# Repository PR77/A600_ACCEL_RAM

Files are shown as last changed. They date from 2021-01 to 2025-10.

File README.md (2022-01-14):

# A600_ACCEL_RAM
Design attempt for an Amiga 600 over CPU (PLCC) 68000 Accelerator including 1.5MB FastRAM (... or is it SlowRAM) and 0.5MB MapROM support.

# Warning
This design has not been compliance tested and will not be. It may cause damage to your A600. I take no responsibility for this. I accept no responsibility for any damage to any equipment that results from the use of this design and its components. IT IS ENTIRELY AT YOUR OWN RISK!

# Overview
The main purpose of this design was to develop a simple, affordable and efficient Accelerator, FastRAM and MapROM support device for the Amiga 600. The main components of the design and the CPU (MC68SEC000), CPLD (9572) and SRAM (CY62167G). There are the odd LEDs for status and some IO Pins for currently unplanned additions. As discovered in my A500 Accelerator the MC68SEC000 can be aggressively clocked and this design does not detour from that.

### Appearance
Nice 3D model:
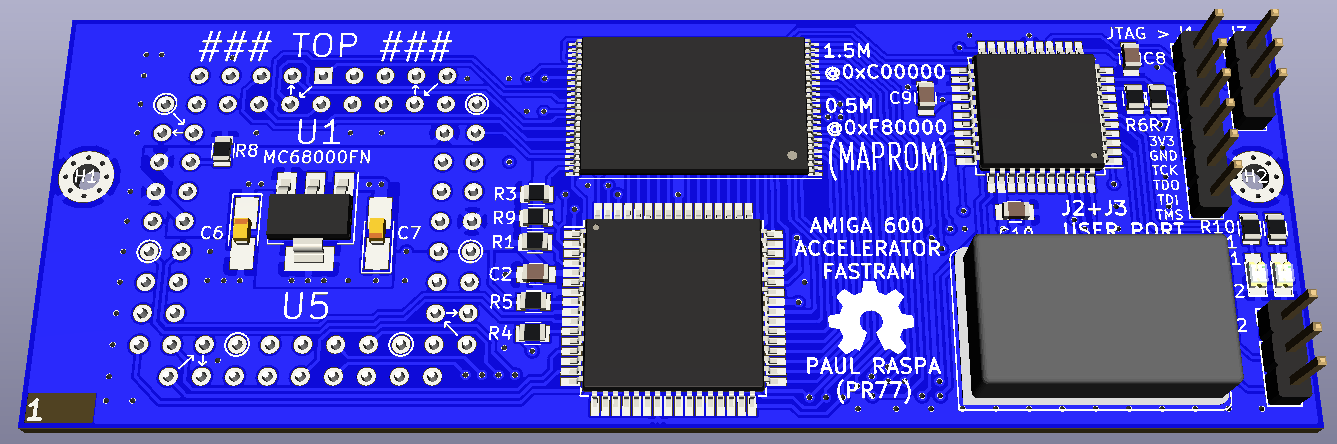
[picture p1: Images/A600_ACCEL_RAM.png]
3D Model


Installed on A600 Motherboard:
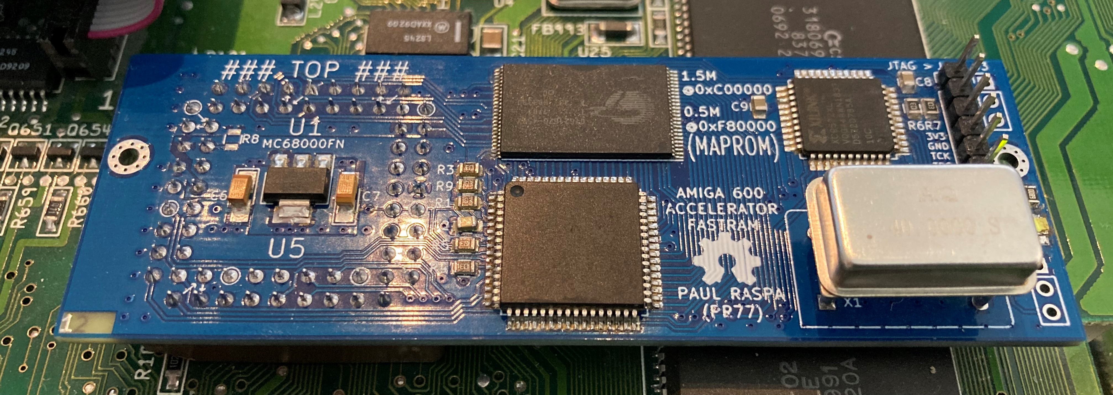
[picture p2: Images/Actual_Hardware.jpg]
Actual Hardware


Mounting holes on the Accelerator PCB match with the HDD cradle and accommodate a M2 screw to provide stress relief for the PLCC68 socket. SukkoPera has a great guide on how to prepare the PLCC68 socket as some small modifications are required. His how to guide is linked here;

https://github.com/SukkoPera/OpenAmiga600FastRamExpansion/blob/master/SocketRework.md

### Performance
Testing has shown that the A600 system is fairly stable at 40MHz. Slower crystals can be used if stability is an issue (let me know if you run into issues). I've had the classic Amiga Juggler running for 48 Hours without any issues. Classic SysInfo shows @ 40MHz (with MapROM active);

* Drystones: 3448
* MIPS: 3.59
* Comment: Only Amiga Makes.. 

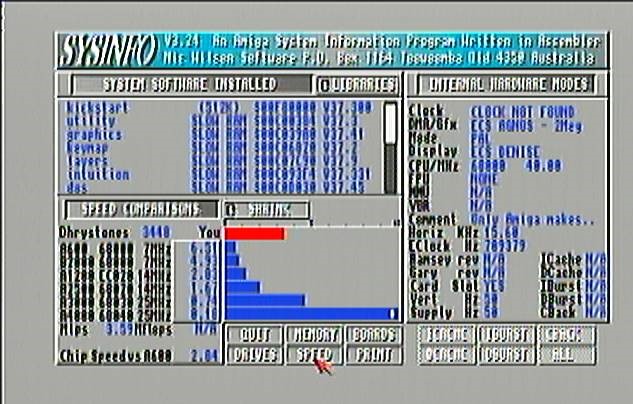
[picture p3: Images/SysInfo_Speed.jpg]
SysInfo Speed


IDE (via GAYLE's scsi.device) also shows a nice speed improvement with a CF Card:

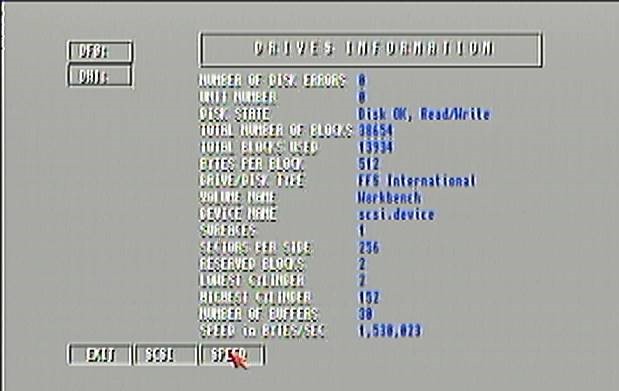
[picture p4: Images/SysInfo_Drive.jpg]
SysInfo Drive


### BOM
For those wanting to build their own hardware, here is the BOM;

| Reference(s)  | Value | Footprint |
|---|---|---|
|C1 | 100n |Capacitors_SMD:C_0805
|C2 | 100n |Capacitors_SMD:C_0805
|C3 | 100n |Capacitors_SMD:C_0805
|C4 | 100n |Capacitors_SMD:C_0805
|C6 | 10u |Capacitors_Tantalum_SMD:CP_Tantalum_Case-R_EIA-2012-12_Hand
|C7 | 10u |Capacitors_Tantalum_SMD:CP_Tantalum_Case-R_EIA-2012-12_Hand
|C8 | 100n |Capacitors_SMD:C_0805
|C9 | 100n |Capacitors_SMD:C_0805
|C10 | 100n |Capacitors_SMD:C_0805
|D1 | LED |LEDs:LED_0805
|D2 | LED |LEDs:LED_0805
|J1 | JTAG |Connector:Conn_01x06_Male","Pin_Headers:Pin_Header_Straight_1x06_Pitch2.54mm
|J2 (not loaded)| SPARE1 |Connector:Conn_01x03_Male","Pin_Headers:Pin_Header_Straight_1x03_Pitch2.54mm
|J3 (not loaded)| SPARE2 |Connector:Conn_01x03_Male","Pin_Headers:Pin_Header_Straight_1x03_Pitch2.54mm
|R1 | 10K |Resistors_SMD:R_0805
|R3 | 10K |Resistors_SMD:R_0805
|R4 | 10K |Resistors_SMD:R_0805
|R5 | 10K |Resistors_SMD:R_0805
|R6 | 10K |Resistors_SMD:R_0805
|R7 | 10K |Resistors_SMD:R_0805
|R8 (not loaded)| 10K |Resistors_SMD:R_0805
|R9 | 10K |Resistors_SMD:R_0805
|R10 | 680R |Resistors_SMD:R_0805
|R11 | 680R |Resistors_SMD:R_0805
|U1 | SOCKET |PLCC-68_THT-SocketUpsideDown
|U2 | MC68SEC000 |Housings_QFP:LQFP-64_14x14mm_Pitch0.8mm
|U3 | CY62167G |Housings_SSOP:TSOP-I-48_18.4x12mm_Pitch0.5mm
|U4 | XC9572VQ44 |Housings_QFP:LQFP-44_10x10mm_Pitch0.8mm
|U5 | LM1117-3.3 |TO_SOT_Packages_SMD:SOT-223-3_TabPin2
|X1 | CXO_DIP14 |Oscillators:Oscillator_DIP-14

### CPU
Regarding the CPU, I purchased from here (I get nothing from this. The parts I received were new and legitimate so I wanted to share the source);

https://www.ebay.de/itm/MC68SEC000FU20-IC-MPU-M680X0-20MHZ-64QFP-NEW/311524970603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

### LED Indicators
2 LED indicators are present:

* ACCEL ACTIVE: This indicates that a Bus Request (BR) was requested by the MC68SEC000 Accelerator CPU and Granted (/BG) by the Amiga's MC68000 CPU.
* MAPROM ACTIVE: After writing a 512K MapROM image to the Accelerator, the next subsequent Reset will active this image. This LED indicates that the MapROM image is in use.

### FastRAM (... or is it SlowRAM)
To simplify the design and keep the CPLD pin count down, I decided not to use traditional FastRAM, rather use SlowRAM which is automatically mapped by the Amiga if valid memory is detected between 0xC00000 - 0xD7FFFF. In this range 1.5MB is available. In this memory range, the Accelerator performs the address decoding and subsequent /DTACK cycle. /AS is not asserted on the Amiga, thus the speed of memory cycles in this range is equivalent to that of FastRAM.

### MapROM
Of the 2MB RAM available, 1.5MB is allocated to SlowRAM and the remainder is allocated for MapROM. MapROM simply works by routing write cycle to 0xF8xxxx directly to the Accelerators RAM. Once enough write cycles are detected (262144 WORD writes), the MapROM write status is latched. After a subsequent Reset, memory accesses to 0xF8xxxx are directly routed to the Accelerators RAM (at full speed) and /AS is not asserted on the Amiga.

To deactive MapROM, simply hold down CTRL-A-A for 1 second and it will be deactivated. A different image could then be loaded. Note, once an image is loaded it needs to be deactivated again before a different image can be used. DiagROM images could also be used - helpful to avoid swapping out the physical ROM chip.

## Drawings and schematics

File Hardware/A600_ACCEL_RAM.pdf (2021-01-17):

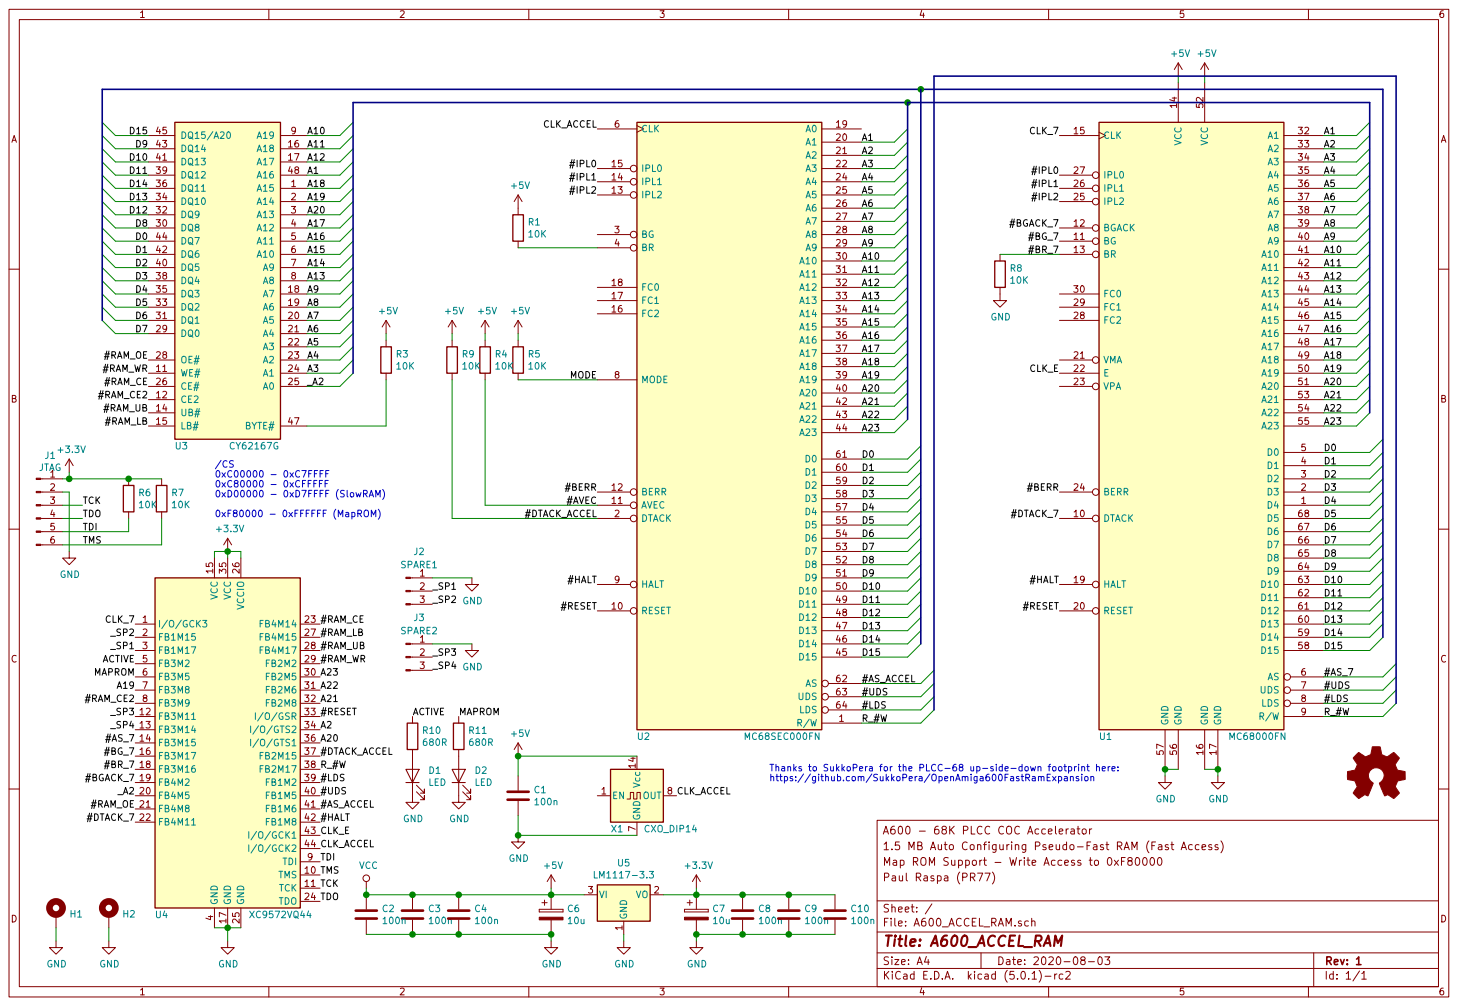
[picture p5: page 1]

Thanks to SukkoPera for the PLCC-68 up-side-down footprint here:

https://github.com/SukkoPera/OpenAmiga600FastRamExpansion VCC

Map ROM Support - Write Access to 0xF80000
File: A600_ACCEL_RAM.sch Sheet: / Paul Raspa (PR77)

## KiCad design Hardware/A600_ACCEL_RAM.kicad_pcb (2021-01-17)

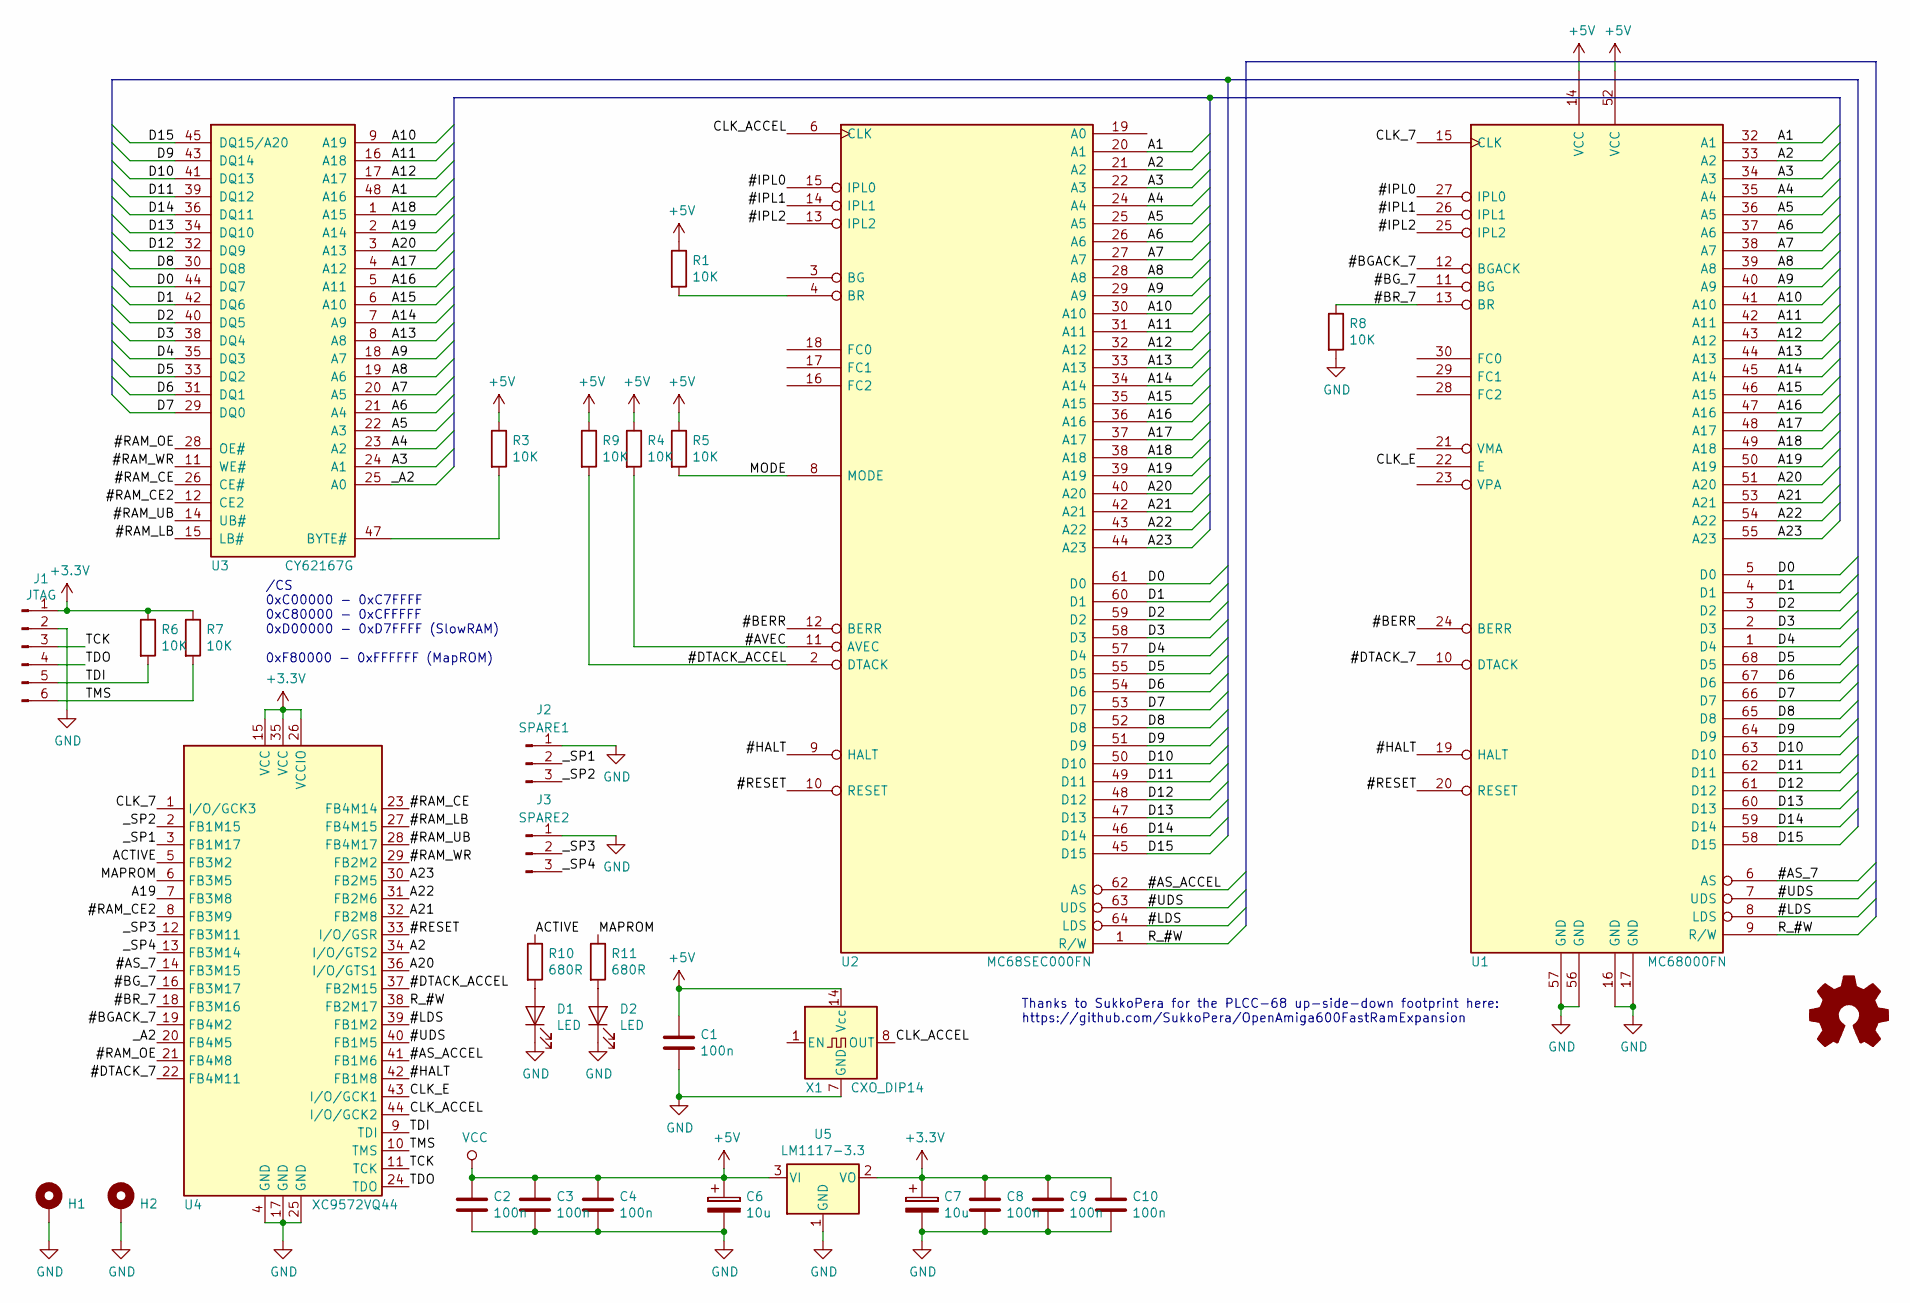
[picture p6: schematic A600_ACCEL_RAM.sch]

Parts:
C1, C2, C3, C4, C8, C9, C10: 100n; C_0805
C6, C7: 10u; CP_Tantalum_Case-R_EIA-2012-12_Hand
D1, D2: LED; LED_0805
H1, H2: MountingHole_Pad; MountingHole_2.2mm_M2_Pad_Via
J1: JTAG; Pin_Header_Straight_1x06_Pitch2.54mm
J2: SPARE1; Pin_Header_Straight_1x03_Pitch2.54mm
J3: SPARE2; Pin_Header_Straight_1x03_Pitch2.54mm
LOGO1: OSHW; OSHW-Symbol_6.7x6mm_SilkScreen
R1, R3, R4, R5, R6, R7, R8, R9: 10K; R_0805
R10, R11: 680R; R_0805
U1: MC68000FN; PLCC-68_THT-SocketUpsideDown
U2: MC68SEC000FN; LQFP-64_14x14mm_Pitch0.8mm
U3: CY62167G; TSOP-I-48_18.4x12mm_Pitch0.5mm
U4: XC9572VQ44; LQFP-44_10x10mm_Pitch0.8mm
U5: LM1117-3.3; SOT-223-3_TabPin2
X1: CXO_DIP14; Oscillator_DIP-14

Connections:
+3V3: C7.1, C8.1, C9.1, C10.1, J1.1, R6.1, R7.1, U4.15 (VCC), U4.26 (VCCIO), U4.35 (VCC), U5.2 (VO)
+5V: C1.1, C2.1, C3.1, C4.1, C6.1, R1.1, R3.1, R4.1, R5.1, R9.1, U1.14 (VCC), U1.52 (VCC), U2.5 (VCC), U2.41 (VCC), U3.37 (VCC), U5.3 (VI), X1.14 (Vcc)
/#AS_7: U1.6 (AS), U4.14 (FB3M15)
/#AS_ACCEL: U2.62 (AS), U4.41 (FB1M6)
/#AVEC: R4.2, U2.11 (AVEC)
/#BERR: U1.24 (BERR), U2.12 (BERR)
/#BGACK_7: U1.12 (BGACK), U4.19 (FB4M2)
/#BG_7: U1.11 (BG), U4.16 (FB3M17)
/#BR_7: R8.1, U1.13 (BR), U4.18 (FB3M16)
/#DTACK_7: U1.10 (DTACK), U4.22 (FB4M11)
/#DTACK_ACCEL: R9.2, U2.2 (DTACK), U4.37 (FB2M15)
/#HALT: U1.19 (HALT), U2.9 (HALT), U4.42 (FB1M8)
/#IPL0: U1.27 (IPL0), U2.15 (IPL0)
/#IPL1: U1.26 (IPL1), U2.14 (IPL1)
/#IPL2: U1.25 (IPL2), U2.13 (IPL2)
/#LDS: U1.8 (LDS), U2.64 (LDS), U4.39 (FB1M2)
/#RAM_CE: U3.26 (CE#), U4.23 (FB4M14)
/#RAM_CE2: U3.12 (CE2), U4.8 (FB3M9)
/#RAM_LB: U3.15 (LB#), U4.27 (FB4M15)
/#RAM_OE: U3.28 (OE#), U4.21 (FB4M8)
/#RAM_UB: U3.14 (UB#), U4.28 (FB4M17)
/#RAM_WR: U3.11 (WE#), U4.29 (FB2M2)
/#RESET: U1.20 (RESET), U2.10 (RESET), U4.33 (I/O/GSR)
/#UDS: U1.7 (UDS), U2.63 (UDS), U4.40 (FB1M5)
/A1: U1.32 (A1), U2.20 (A1), U3.48 (A16)
/A2: U1.33 (A2), U2.21 (A2), U4.34 (I/O/GTS2)
/A3: U1.34 (A3), U2.22 (A3), U3.24 (A1)
/A4: U1.35 (A4), U2.24 (A4), U3.23 (A2)
/A5: U1.36 (A5), U2.25 (A5), U3.22 (A3)
/A6: U1.37 (A6), U2.26 (A6), U3.21 (A4)
/A7: U1.38 (A7), U2.27 (A7), U3.20 (A5)
/A8: U1.39 (A8), U2.28 (A8), U3.19 (A6)
/A9: U1.40 (A9), U2.29 (A9), U3.18 (A7)
/A10: U1.41 (A10), U2.30 (A10), U3.9 (A19)
/A11: U1.42 (A11), U2.31 (A11), U3.16 (A18)
/A12: U1.43 (A12), U2.32 (A12), U3.17 (A17)
/A13: U1.44 (A13), U2.33 (A13), U3.8 (A8)
/A14: U1.45 (A14), U2.34 (A14), U3.7 (A9)
/A15: U1.46 (A15), U2.35 (A15), U3.6 (A10)
/A16: U1.47 (A16), U2.36 (A16), U3.5 (A11)
/A17: U1.48 (A17), U2.37 (A17), U3.4 (A12)
/A18: U1.49 (A18), U2.38 (A18), U3.1 (A15)
/A19: U1.50 (A19), U2.39 (A19), U3.2 (A14), U4.7 (FB3M8)
/A20: U1.51 (A20), U2.40 (A20), U3.3 (A13), U4.36 (I/O/GTS1)
/A21: U1.53 (A21), U2.42 (A21), U4.32 (FB2M8)
/A22: U1.54 (A22), U2.43 (A22), U4.31 (FB2M6)
/A23: U1.55 (A23), U2.44 (A23), U4.30 (FB2M5)
/ACTIVE: R10.1, U4.5 (FB3M2)
/CLK_7: U1.15 (CLK), U4.1 (I/O/GCK3)
/CLK_ACCEL: U2.6 (CLK), U4.44 (I/O/GCK2), X1.8 (OUT)
/CLK_E: U1.22 (E), U4.43 (I/O/GCK1)
/D0: U1.5 (D0), U2.61 (D0), U3.44 (DQ7)
/D1: U1.4 (D1), U2.60 (D1), U3.42 (DQ6)
/D2: U1.3 (D2), U2.59 (D2), U3.40 (DQ5)
/D3: U1.2 (D3), U2.58 (D3), U3.38 (DQ4)
/D4: U1.1 (D4), U2.57 (D4), U3.35 (DQ3)
/D5: U1.68 (D5), U2.55 (D5), U3.33 (DQ2)
/D6: U1.67 (D6), U2.54 (D6), U3.31 (DQ1)
/D7: U1.66 (D7), U2.53 (D7), U3.29 (DQ0)
/D8: U1.65 (D8), U2.52 (D8), U3.30 (DQ8)
/D9: U1.64 (D9), U2.51 (D9), U3.43 (DQ14)
/D10: U1.63 (D10), U2.50 (D10), U3.41 (DQ13)
/D11: U1.62 (D11), U2.49 (D11), U3.39 (DQ12)
/D12: U1.61 (D12), U2.48 (D12), U3.32 (DQ9)
/D13: U1.60 (D13), U2.47 (D13), U3.34 (DQ10)
/D14: U1.59 (D14), U2.46 (D14), U3.36 (DQ11)
/D15: U1.58 (D15), U2.45 (D15), U3.45 (DQ15/A20)
/MAPROM: R11.1, U4.6 (FB3M5)
/MODE: R5.2, U2.8 (MODE)
/R_#W: U1.9 (R/W), U2.1 (R/W), U4.38 (FB2M17)
/TCK: J1.3, U4.11 (TCK)
/TDI: J1.5, R6.2, U4.9 (TDI)
/TDO: J1.4, U4.24 (TDO)
/TMS: J1.6, R7.2, U4.10 (TMS)
/_A2: U3.25 (A0), U4.20 (FB4M5)
/_SP1: J2.2, U4.3 (FB1M17)
/_SP2: J2.3, U4.2 (FB1M15)
/_SP3: J3.2, U4.12 (FB3M11)
/_SP4: J3.3, U4.13 (FB3M14)
GND: C1.2, C2.2, C3.2, C4.2, C6.2, C7.2, C8.2, C9.2, C10.2, D1.1 (K), D2.1 (K), H1.1, H2.1, J1.2, J2.1, J3.1, R8.2, U1.16 (GND), U1.17 (GND), U1.56 (GND), U1.57 (GND), U2.7 (GND), U2.23 (GND), U2.56 (GND), U3.27 (GND), U3.46 (GND), U4.4 (GND), U4.17 (GND), U4.25 (GND), U5.1 (GND), X1.7 (GND)
unnamed: D1.2 (A), R10.2
unnamed: D2.2 (A), R11.2
unnamed: R1.2, U2.4 (BR)
unnamed: R3.2, U3.47 (BYTE#)

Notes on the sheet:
Thanks to SukkoPera for the PLCC-68 up-side-down footprint here: https://github.com/SukkoPera/OpenAmiga600FastRamExpansion
/CS 0xC00000 - 0xC7FFFF 0xC80000 - 0xCFFFFF 0xD00000 - 0xD7FFFF (SlowRAM) 0xF80000 - 0xFFFFFF (MapROM)

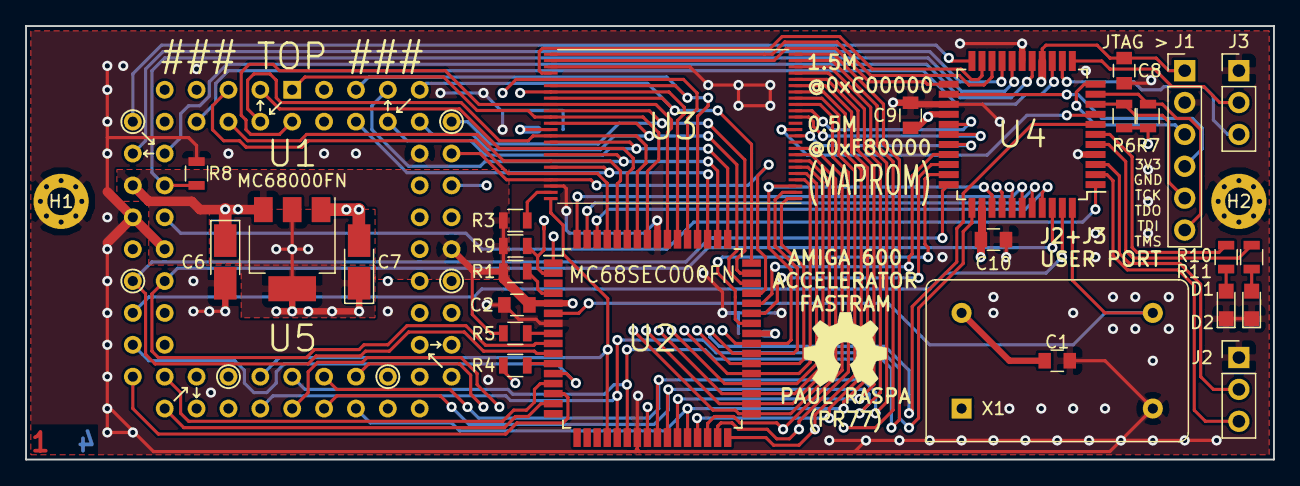
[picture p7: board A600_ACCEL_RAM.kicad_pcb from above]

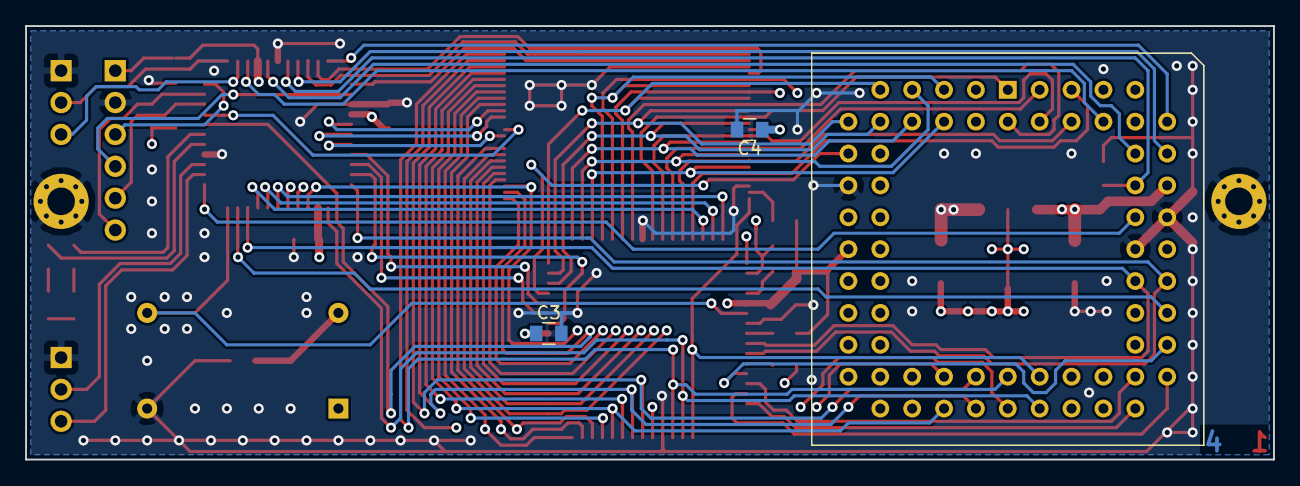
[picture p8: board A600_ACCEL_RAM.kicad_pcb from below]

Board: 4 copper layers, 99.4 x 34.5 mm, 33 parts (2 on the bottom side), 84 nets.

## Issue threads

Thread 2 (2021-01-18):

Vcc for U2 and U3 missing from schematic

Eriond, 2021-01-18:
I was merely curious whether you were running the 68SEC from the 3V3 or 5V0 rail? (Since it's capable of both)

PR77, 2021-01-18:
5 volts. The nodes are hidden by default for the schematic components.

Closed 2021-01-18.

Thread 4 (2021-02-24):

More fastram?

culexus8, 2021-02-24:
Will it be possible upgrade it so it can have more fastram?

PR77, 2021-02-24:
A redesign (CPLD + PCB) would be required. The CPLD and memory mapping logic is such that C00000-D7FFFF is mapped therefore the necessary address lines are only routed. I will do this when more time becomes available to me.

Closed 2021-02-24.

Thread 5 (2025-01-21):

Wrong voltage for RAM part .

levo-man, 2025-01-21:
You have specified the 'G' version of the ram that is connected to 5v , this is a 3.3v part . The 'ELL' version of this ram is 5v .

levo-man, 2025-06-24:
[CY62167G.PDF](https://github.com/user-attachments/files/20885507/CY62167G.PDF)

On this datasheet ( the only one that I could find ) .

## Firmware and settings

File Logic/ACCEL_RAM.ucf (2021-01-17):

#PACE: Start of Constraints generated by PACE

#PACE: Start of PACE I/O Pin Assignments
NET "_A2"  LOC = "P20"  ;
NET "A2"  LOC = "P34"  ;
NET "ACCEL_ACTIVE"  LOC = "P5"  ; 
NET "ADDRESS<19>"  LOC = "P7"  ; 
NET "ADDRESS<20>"  LOC = "P36"  ;
NET "ADDRESS<21>"  LOC = "P32"  ;
NET "ADDRESS<22>"  LOC = "P31"  ;
NET "ADDRESS<23>"  LOC = "P30"  ;
NET "AS_7"  LOC = "P14"  ; 
NET "AS_ACCEL"  LOC = "P41"  ;
NET "BG_7"  LOC = "P16"  ; 
NET "BGACK_7"  LOC = "P19"  ; 
NET "BR_7"  LOC = "P18"  ; 
NET "CLK_7"  LOC = "P1"  ; 
NET "CLK_ACCEL"  LOC = "P44"  ;
NET "CLK_E"  LOC = "P43"  ;
NET "DTACK_7"  LOC = "P22"  ;
NET "DTACK_ACCEL"  LOC = "P37"  ;
NET "HALT"  LOC = "P42"  ;
NET "IO_PORT<0>"  LOC = "P3"  ; 
NET "IO_PORT<1>"  LOC = "P2"  ; 
NET "IO_PORT<2>"  LOC = "P12"  ; 
NET "IO_PORT<3>"  LOC = "P13"  ; 
NET "LDS"  LOC = "P39"  ;
NET "MAPROM_ACTIVE"  LOC = "P6"  ; 
NET "r_RAM_CE2"  LOC = "P8"  ;
NET "r_RAM_CE_n"  LOC = "P23"  ;
NET "r_RAM_LB_n"  LOC = "P27"  ;
NET "r_RAM_OE_n"  LOC = "P21"  ;
NET "r_RAM_UB_n"  LOC = "P28"  ;
NET "r_RAM_WR_n"  LOC = "P29"  ;
NET "RESET"  LOC = "P33"  ;
NET "RW"  LOC = "P38"  ;
NET "UDS"  LOC = "P40"  ;

#PACE: Start of PACE Area Constraints

#PACE: Start of PACE Prohibit Constraints

#PACE: End of Constraints generated by PACE

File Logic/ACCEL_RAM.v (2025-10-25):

`timescale 1ns / 1ps
/*
    This file is part of A600_ACCEL_RAM originally designed by
    Paul Raspa 2020.

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
    Revision 0.0 - 17.09.2020:
    Initial revision.
    
    Revision 1.0 - 07.01.2021:
    Updated for revised PCB layout.
*/

`define FASTRAM_ACCESS_1WS

module ACCEL_RAM(

    // CPU
    input RESET,
    input HALT,
    
    input CLK_E,
    input CLK_7,
    input CLK_ACCEL,
    
    input AS_ACCEL,
    output AS_7,
       
    input DTACK_7,
    output DTACK_ACCEL,
    
    //--- BR_7 Input if 3 Wire Bus Arbitration would be used
    //input BR_7,
    //---
    output BR_7,
    input BG_7,
    output BGACK_7,

    input RW,
    input LDS,
    input UDS,
    
    // RAM
    output r_RAM_CE2,
    output reg r_RAM_CE_n,
    output reg r_RAM_OE_n,
    output reg r_RAM_LB_n,
    output reg r_RAM_UB_n,
    output reg r_RAM_WR_n,
    
    // LEDs
    output ACCEL_ACTIVE,
    output MAPROM_ACTIVE,
    
    // SPAREs
    output [3:0] IO_PORT,
    
    // Address bus
    input [23:19] ADDRESS,
    input A2,
    output _A2

    );
    
// --- Control signals

wire DS = !(LDS || UDS);
wire ACCESS = (!AS_ACCEL && RESET);
wire OVERLAY_RANGE = ({ADDRESS[23:19]} == {5'h00}) && ACCESS;                                   // 0x000000 - 0x0EFFFF
wire CIA_RANGE = ({ADDRESS[23:19]} == {5'h17}) && ACCESS;                                       // 0xBF0000 - 0xBFFFFF
wire SLOWRAM_RANGE = ({ADDRESS[23:19]} >= {5'h18} && {ADDRESS[23:19]} <= {5'h1A}) && ACCESS;    // 0xC00000 - 0xD7FFFF
wire MAPROM_RANGE = ({ADDRESS[23:19]} == {5'h1F}) && ACCESS;                                    // 0xF80000 - 0xFFFFFF

// --- Bus Master Control

// This implements 3-wire handshaking according to Figure 5-13. 3-Wire Bus Arbitration Cycle Flowchart

/*
reg r_acceleratorActive = 1'b0;
reg r_busRequested = 1'b0;

always @(posedge CLK_7 or negedge RESET) begin : BUS_MASTER_CONTROL_3WIRE
    
    if (!RESET) begin
        r_acceleratorActive <= 1'b0;
        r_busRequested <= 1'b1;
    end else begin
    
        if (BG_7 == 1'b0 && AS_ACCEL == 1'b1 && r_acceleratorActive == 1'b0) begin
            r_acceleratorActive <= 1'b1;
            r_busRequested <= 1'b0;
        end
    end
end

assign BR_7 = (r_busRequested) ? 1'b0 : 1'b1;
assign BGACK_7 = (r_acceleratorActive) ? 1'b0 : 1'b1;
assign ACCEL_ACTIVE = r_acceleratorActive;
*/

// This implements 2-wire handshaking according to Figure 5-14. 2-Wire Bus Arbitration Cycle Flowchart

assign BR_7 = 1'b0;
assign BGACK_7 = 1'bZ;
assign ACCEL_ACTIVE = (RESET & !BG_7);

// --- CIA Access Detection

reg r_overlay = 1'b0;

always @(posedge AS_ACCEL or negedge RESET) begin : CIA_ACCESS

    // detect if the CIA access has occured after reset to determine when ROM overlay is disbaled

    if (!RESET) begin
        r_overlay <= 1'b0;
    end else begin
    
        if (CIA_RANGE == 1'b1) begin
            r_overlay <= 1'b1;
        end
    end
end

// --- MAPROM Control

reg r_initialiseColdBoot = 1'b0;
reg r_mapROMWritten = 1'b0;
reg r_mapROMEnabled = 1'b0;
reg [17:0] r_addressCounter = 18'd0;
reg [19:0] r_clockCounter = 20'd0;

always @(posedge DS or negedge RESET) begin : MAPROM_CONTROL

    // count the number of MAPROM_RANGE word sized writes to determine if 512KBytes have been written

    if (!RESET) begin
        r_addressCounter <= 18'd0;
        
        if (&r_clockCounter) begin
            r_mapROMWritten <= 1'b0;
            r_mapROMEnabled <= 1'b0;
        end else begin
        
            if (r_mapROMWritten == 1'b1) begin
                r_mapROMEnabled <= 1'b1;
            end
        end
    end else begin
    
        if (MAPROM_RANGE == 1'b1 && !RW) begin
            if (!r_initialiseColdBoot) begin
                r_mapROMWritten <= 1'b0;
                r_mapROMEnabled <= 1'b0;
                r_initialiseColdBoot <= 1'b1;
            end
        
            r_addressCounter <= r_addressCounter + 18'd1;
            
            if (&r_addressCounter) begin
                r_mapROMWritten <= 1'b1;
            end
        end
    end
end

assign MAPROM_ACTIVE = r_mapROMEnabled;

// --- MAPROM Reset Control

wire CLOCK_COUNTER_EXPIRED = &r_clockCounter;

always @(posedge CLK_E or posedge RESET) begin : MAPROM_RESET_CONTROL

    // count E_CLK cycles for approx. 1 second to clear MapROM latch when /RESET is asserted

    if (RESET) begin
        r_clockCounter <= 20'd0;
    end else begin
    
        if (!CLOCK_COUNTER_EXPIRED) begin
            r_clockCounter <= r_clockCounter + 20'd1;
        end
    end
end

// --- RAM Control

assign r_RAM_CE2 = 1'b1;
reg r_RAMCycleComplete = 1'b0;
reg [1:0] r_stRAMControl = 2'b00;

always @(negedge CLK_ACCEL or posedge AS_ACCEL) begin : RAM_CONTROL

    if (AS_ACCEL) begin
        r_RAM_CE_n <= 1'b1;
        r_RAM_OE_n <= 1'b1;
        r_RAM_LB_n <= 1'b1;
        r_RAM_UB_n <= 1'b1;
        r_RAM_WR_n <= 1'b1;
        r_RAMCycleComplete <= 1'b0;
        r_stRAMControl <= 2'b00;
    end else begin

        case (r_stRAMControl)

        2'b00: begin
            if (SLOWRAM_RANGE == 1'b1) begin
                r_RAM_CE_n <= 1'b0;
                r_stRAMControl <= 2'b01;
            end

            if (MAPROM_RANGE == 1'b1) begin
                r_RAM_CE_n <= 1'b0;
                r_stRAMControl <= 2'b10;
            end
        end

        2'b01: begin
            // Read & Write Cycle for SLOW RAM space
            if (LDS == 1'b0 || UDS == 1'b0) begin
                r_RAM_OE_n <= (RW) ? 1'b0 : 1'b1;
                r_RAM_LB_n <= LDS;
                r_RAM_UB_n <= UDS;
                r_RAM_WR_n <= (!RW) ? 1'b0 : 1'b1;

                `ifdef FASTRAM_ACCESS_1WS 
                    r_stRAMControl <= 2'b11;
                `else
                    // acknowledge RAM cycle complete directly to improve performance
                    r_stRAMControl <= 2'b00;
                    r_RAMCycleComplete <= 1'b1;
                `endif
            end
        end

        2'b10: begin
            // Read & Write Cycle for MAPROM space
            if (LDS == 1'b0 || UDS == 1'b0) begin
                r_RAM_OE_n <= (RW && r_mapROMEnabled) ? 1'b0 : 1'b1;
                r_RAM_LB_n <= LDS;
                r_RAM_UB_n <= UDS;
                r_RAM_WR_n <= (!RW && !r_mapROMWritten) ? 1'b0 : 1'b1;

                `ifdef FASTRAM_ACCESS_1WS 
                    r_stRAMControl <= 2'b11;
                `else
                    // acknowledge RAM cycle complete directly to improve performance
                    r_stRAMControl <= 2'b00;
                    r_RAMCycleComplete <= 1'b1;
                `endif
            end
        end

        2'b11: begin
            // DTACK Cycle
            r_stRAMControl <= 2'b00;
            r_RAMCycleComplete <= 1'b1;
        end

        default:
            r_stRAMControl <= 2'b00;

        endcase
        end
end

// Assign directly _A2 to A2. Address line A2 for the RAM is routed through the CPLD for
// simple PCB routing.
assign _A2 = A2;

// --- Accelerator
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

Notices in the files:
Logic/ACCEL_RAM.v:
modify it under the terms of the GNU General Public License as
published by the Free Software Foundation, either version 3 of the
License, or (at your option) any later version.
